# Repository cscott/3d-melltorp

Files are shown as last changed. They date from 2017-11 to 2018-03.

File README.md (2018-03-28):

# Enclosure for 3d printer based on Ikea Melltorp tables

Thing tracker at:
https://cscott.github.io/thing-tracker/#/thing/6400396d-9777-424c-8209-8ab2d352c14b

## Description

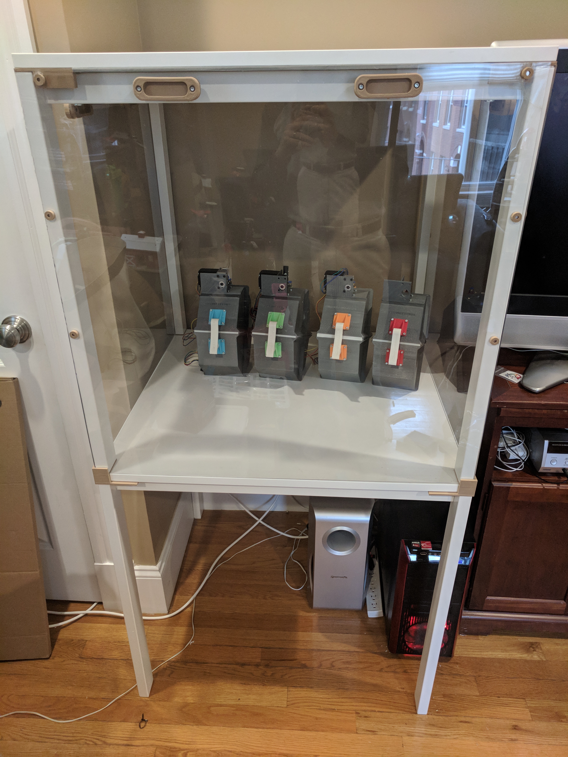
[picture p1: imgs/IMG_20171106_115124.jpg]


This repository contains a collection of parts used to create a 29.5"
x 29.5" 3D printer enclosure based on IKEA [Melltorp] tables.  It was
inspired by the many similar designs for enclosures based on the IKEA
[Lack] tables, but my modified Printrbot Simple Metal printer is a bit
too large to fit in the 22" x 22" space provided by the Lack.

You will need two Melltorp tables.  You could probably stack these
three high if you wanted an enclosure for two printers.

<br clear="both" />

## Instructions

### Step 1: Assemble bottom table.

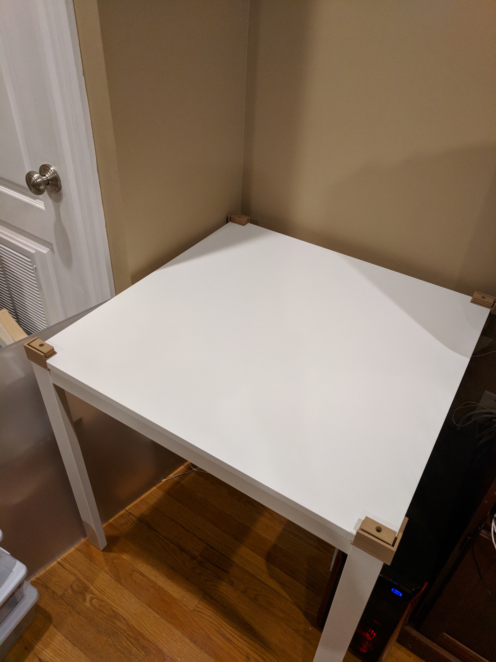
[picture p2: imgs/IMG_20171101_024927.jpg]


Follow the Ikea instructions for assembling the bottom table.  After
assembly, flip the table upright and unscrew the four allen-head bolts
attaching the tabletop to the leg assembly.  Slide four printer leg
holder pieces ([`melltorp-above-wrap.stl`]; 2 of these will need to be
mirrored) over the corners of the
table, inserting the white Ikea spacers into the cutouts provided,
then reattach the tabletop using the allen-head bolts.

<br clear="both" />
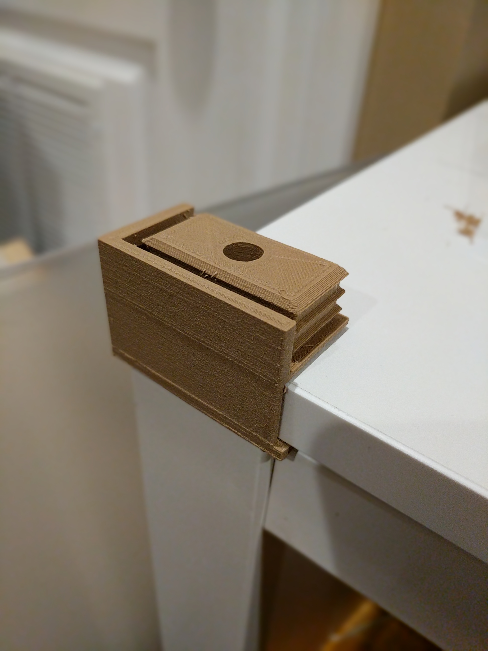
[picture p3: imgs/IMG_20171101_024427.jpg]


Alternatively, you could use [`melltorp-above.stl`] and screw the leg
holders directly into the table top. (Again, two should be printed out
as mirror images.)

<br clear="both" />

### Step 2: Assemble top table.

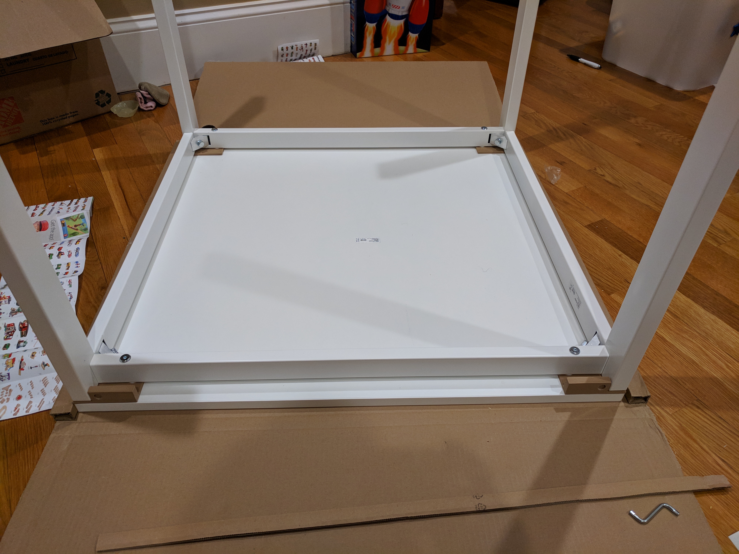
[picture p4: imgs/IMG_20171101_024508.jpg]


Again, follow the Ikea instructions to assemble the top table, but
sandwich the four magnet holders ([`melltorp-below.stl`], 2 will be mirrored)
between the
legs and tabletop, using the white Ikea spacers in the provided
cutouts for alignment. I also recommend using [foam sealing tape]
between the table frame and table top to seal the gap.

<br clear="both" />
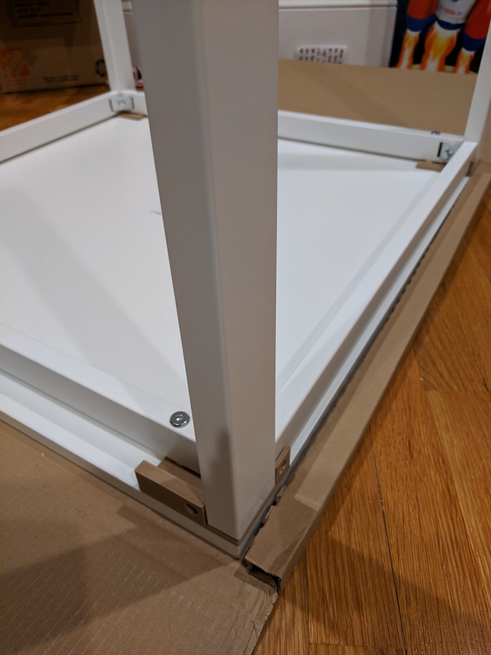
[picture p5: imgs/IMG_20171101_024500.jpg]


<br clear="both" />

### Step 3: Stack the tables

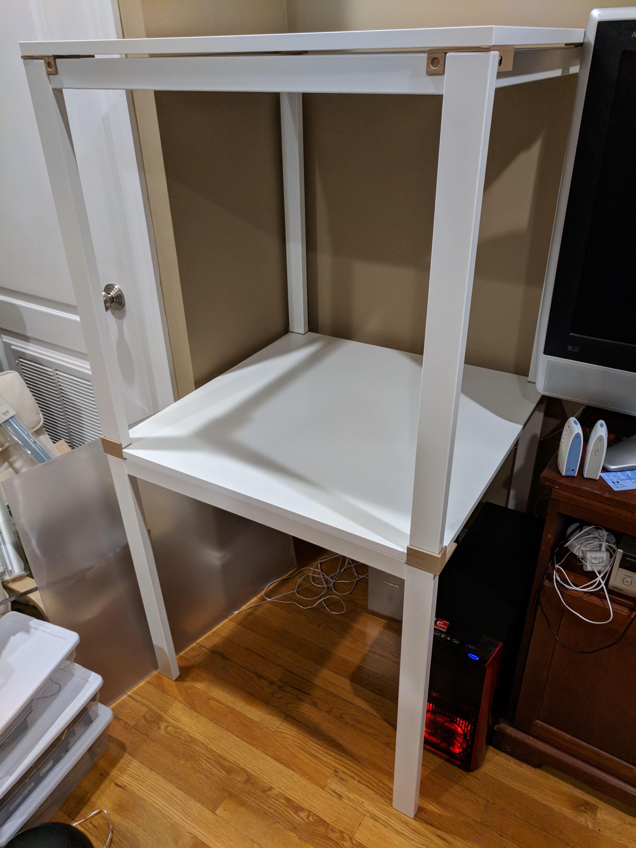
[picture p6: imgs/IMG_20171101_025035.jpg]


Pry off the white plastic caps on the end of each leg on the top
table, then stack the top table on top of the bottom table.

<br clear="both" />

### Step 4: Trim plexiglass

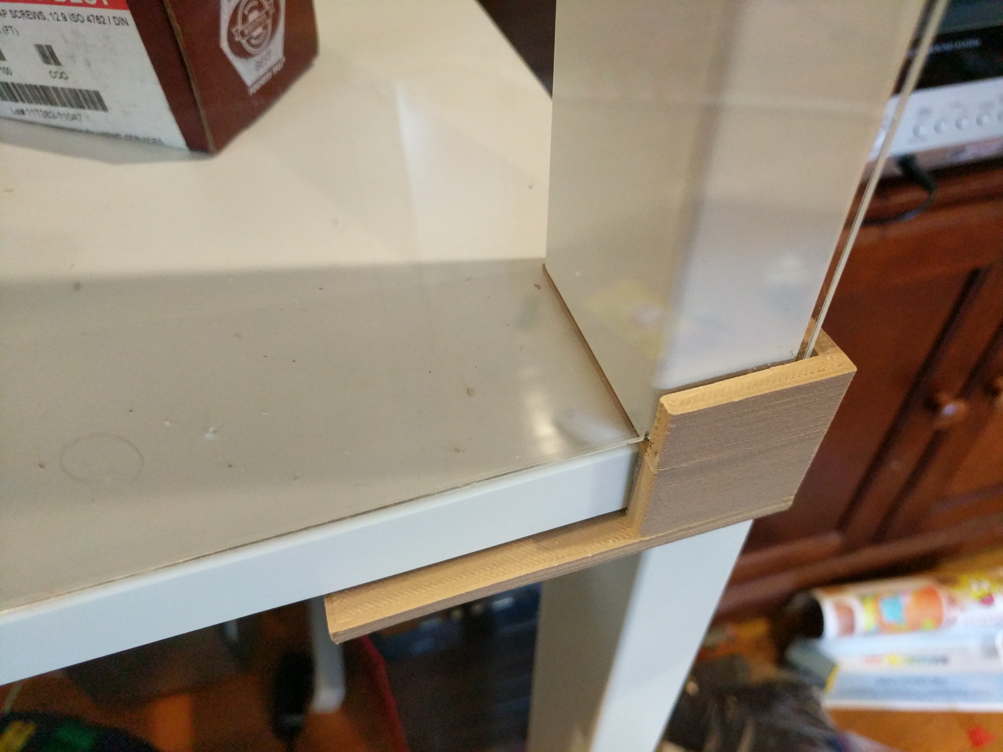
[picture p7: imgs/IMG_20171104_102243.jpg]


Trim 4 sheets of [28"x30" plexiglass] to 28" x 29.25".  (Note that the
link goes to Lowe's, which sells "30in x 30in" sheets of plexiglass
which are really 28" x 30".  If you get your plexiglass from a
different source, you might want to extend the 28" side up to 28.5"
for a better seal.)

The bottom of the plexiglass will slide into the space between the
table legs and the leg holder.

<br clear="both" />

### Step 5: Install magnets

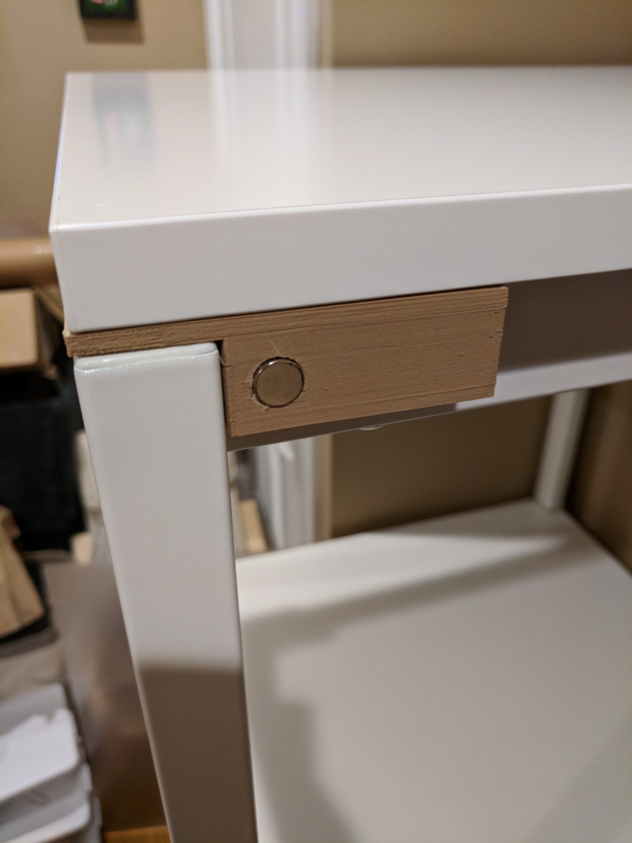
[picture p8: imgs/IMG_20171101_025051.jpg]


Insert magnets into the indents by the table legs.  Take care to
ensure the polarities of the magnets are consistent.

<br clear="both" />
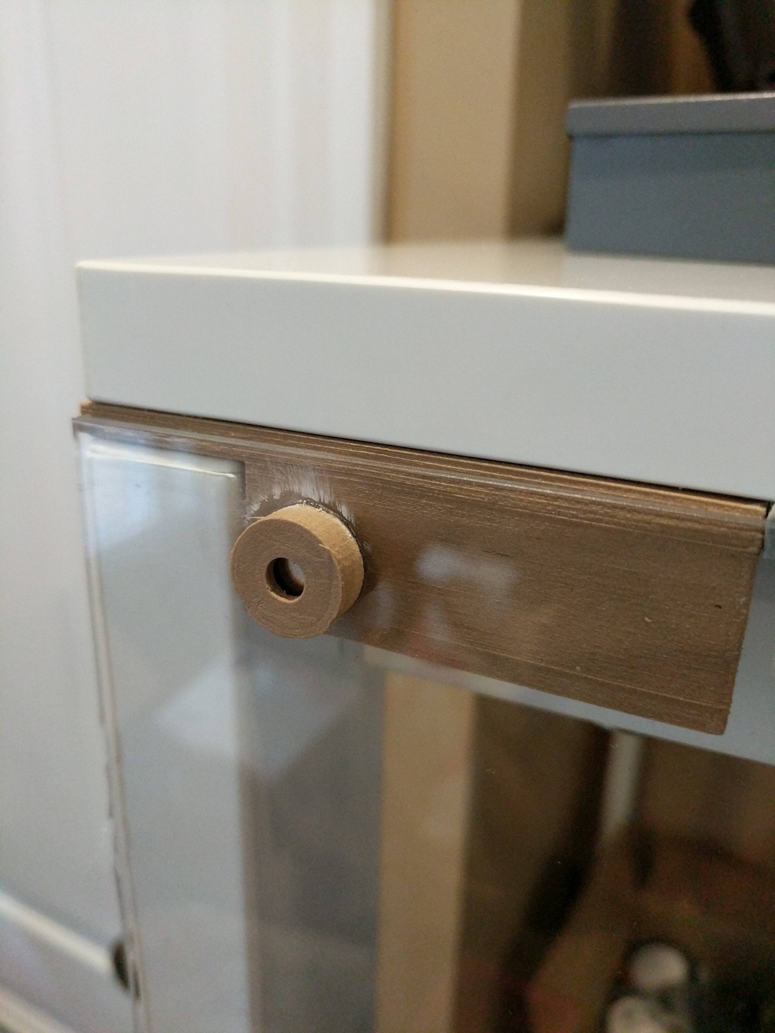
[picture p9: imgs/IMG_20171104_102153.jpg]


Now insert
magnets into the magnet mount rings ([`melltorp-holder.stl`]), again
taking care to ensure that the polarity is consistent and that the
open end of the mount ring is attracted to the open side of the table
leg magnets.  Slide the plexiglass into the channels at the bottom,
and use the mounted magnets to secure the top of the plexiglass.  Use
some superglue to affix the magnet mounts permanently to the
plexiglass once you have things lined up.

<br clear="both" />
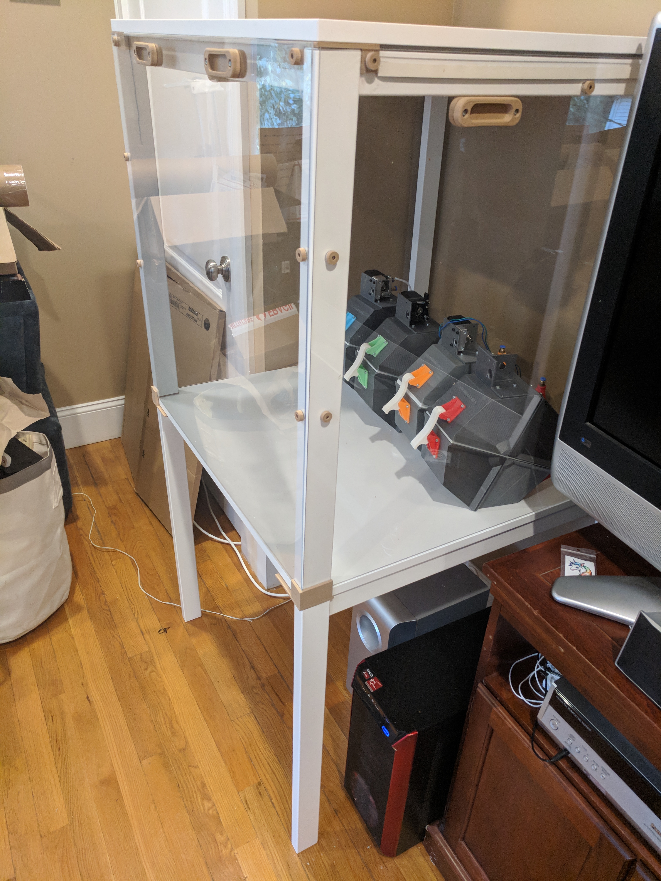
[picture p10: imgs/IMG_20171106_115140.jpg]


I also added a pair of mounted magnets 8" and 16" down from the top
of the leg, in order to better seal the sides of the plexiglass.
For the side pieces, I added some [foam sealing tape], and superglued
one magnet directly to the table frame.  A mounted magnet glued to
the plexiglass at this same spot helps keep the plexiglass pressed
into the foam tape.

<br clear="both" />

### Step 6: Install handles

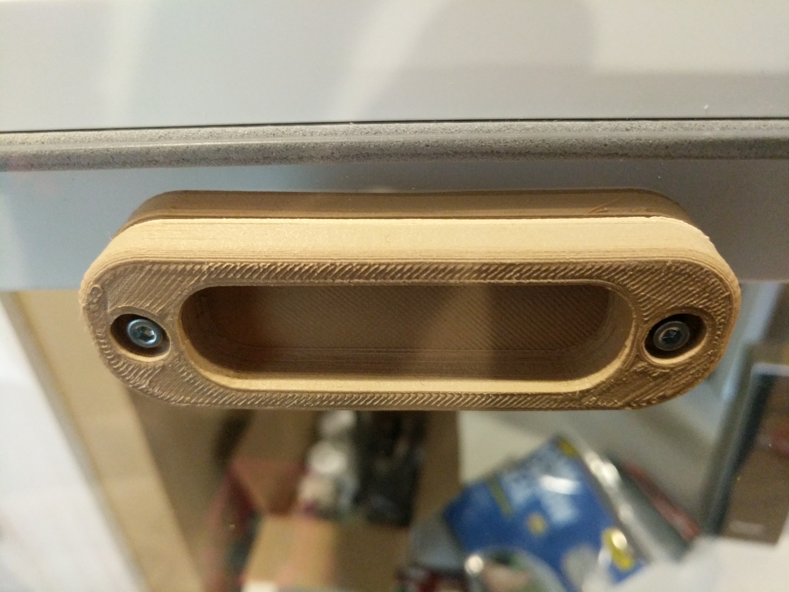
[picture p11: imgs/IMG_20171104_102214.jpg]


Use M3 x 12mm socket head screws and M3 nuts to attach handles
([`melltorp-handle-top.stl`]) to either side of the plexiglass.
Note that I had some issues with the plexiglass cracking when I
drilled the screw holes for mounting; I recommend supergluing
one side to the plexiglass and then using it as a guide when
drilling.  The glued side would prevent any crack from spreading,
but it also seems to prevent cracking in the first place.

<br clear="both" />
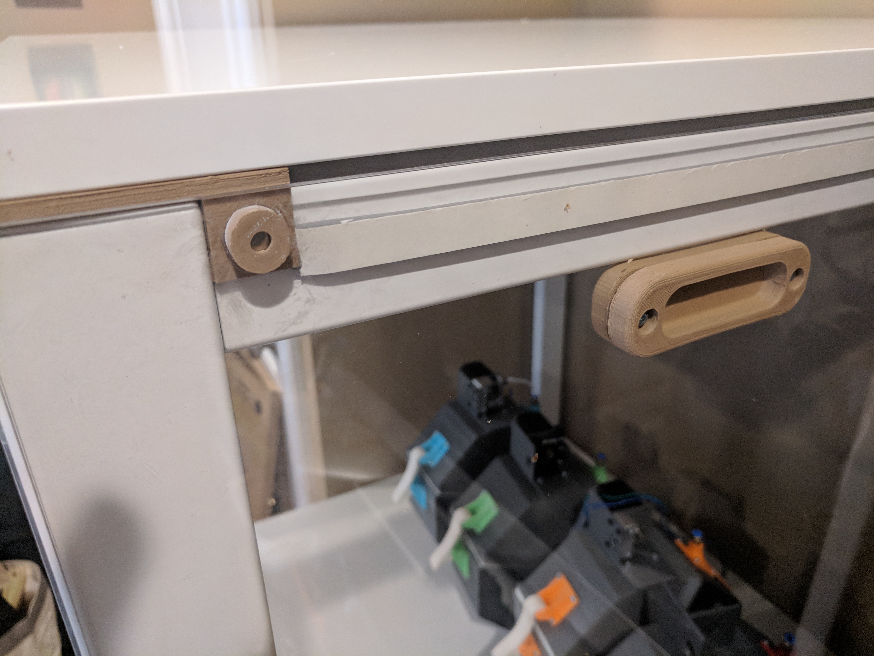
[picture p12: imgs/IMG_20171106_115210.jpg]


I find it most convenient to have a handle for gripping on both
sides of the plexiglass, so I can easily lift the sheets into
place or out of the way, but if you want to save some printing
time you can glue handles on only one side, or else use
[`melltorp-handle-bottom.stl`] on the back side.

<br clear="both" />

## Related

* [An excellent printer enclosure using a Lack table](https://www.thingiverse.com/thing:1843235).

## License

These designs are licensed under the [GPLv2+].

[Lack]: http://www.ikea.com/us/en/catalog/products/20011408/
[Melltorp]: http://www.ikea.com/us/en/catalog/products/S39011781/
[28"x30" plexiglass]: https://www.lowes.com/pd/OPTIX-0-08-in-x-30-in-x-30-in-Clear-Acrylic-Sheet/3978817
[10x3mm magnets]: https://amazon.com/gp/product/B01MFHNHNW/
[foam sealing tape]: https://amazon.com/gp/product/B00005202Y
[`melltorp-above-wrap.stl`]: ./melltorp-stl/melltorp-above-wrap.stl
[`melltorp-above.stl`]: ./melltorp-stl/melltorp-above.stl
[`melltorp-below.stl`]: ./melltorp-stl/melltorp-below.stl
[`melltorp-holder.stl`]: ./melltorp-stl/melltorp-holder.stl
[`melltorp-handle-top.stl`]: ./melltorp-stl/melltorp-handle-top.stl
[`melltorp-handle-bottom.stl`]: ./melltorp-stl/melltorp-handle-bottom.stl
[GPLv2+]: https://spdx.org/licenses/GPL-2.0+.html

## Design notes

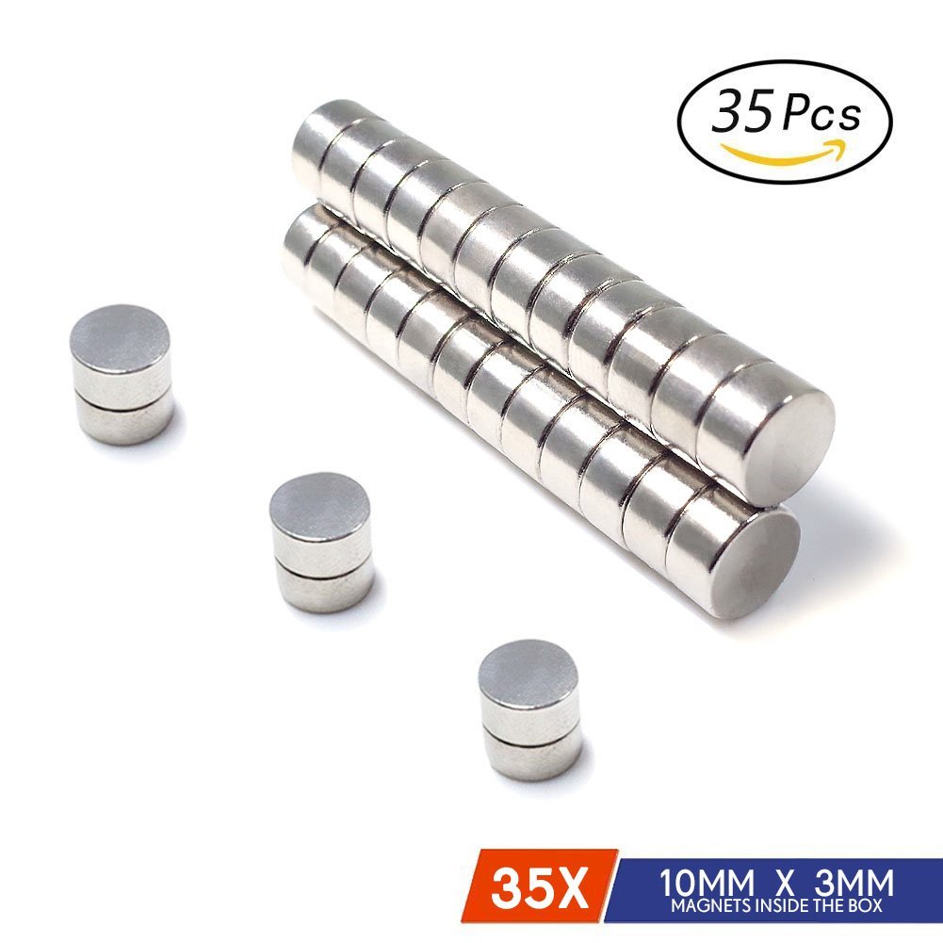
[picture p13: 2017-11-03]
imgs/magnets.jpg

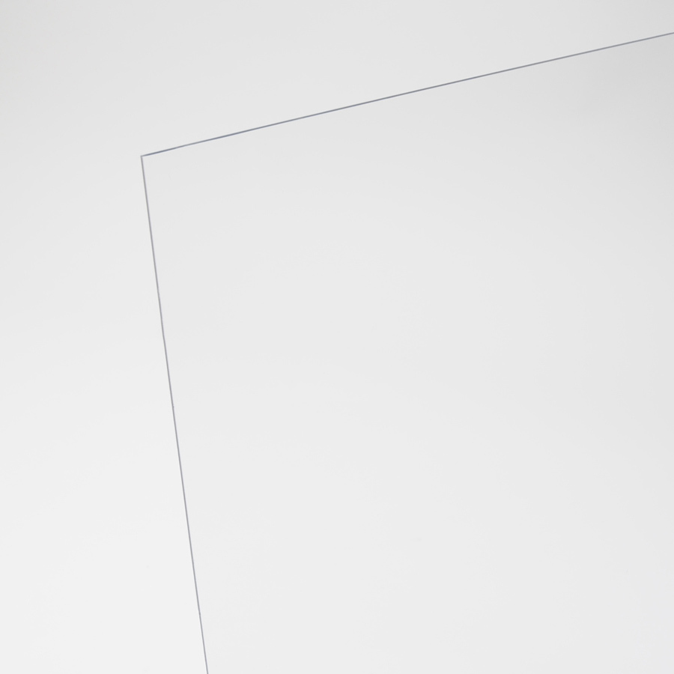
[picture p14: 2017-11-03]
imgs/plexiglass.jpg

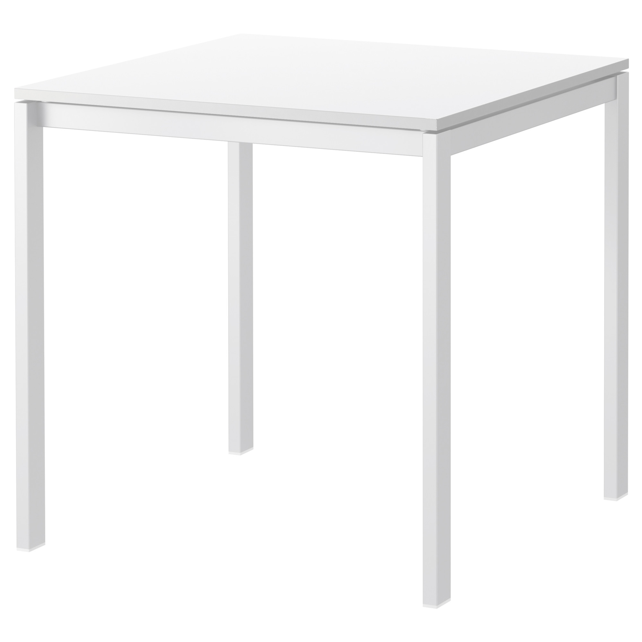
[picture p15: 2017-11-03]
imgs/melltorp.jpg

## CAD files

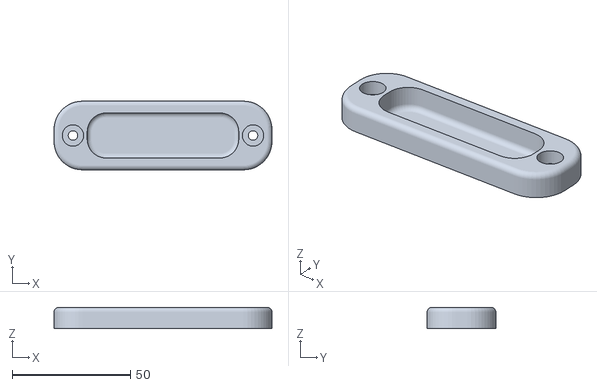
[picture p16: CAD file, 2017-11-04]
melltorp-stl/melltorp-handle-top.stl
92.0 x 29.0 x 9.00

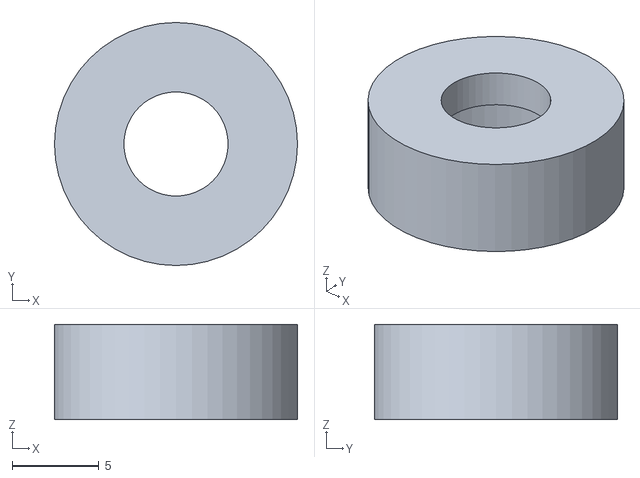
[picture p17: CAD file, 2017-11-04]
melltorp-stl/melltorp-holder.stl
14.0 x 14.0 x 5.50

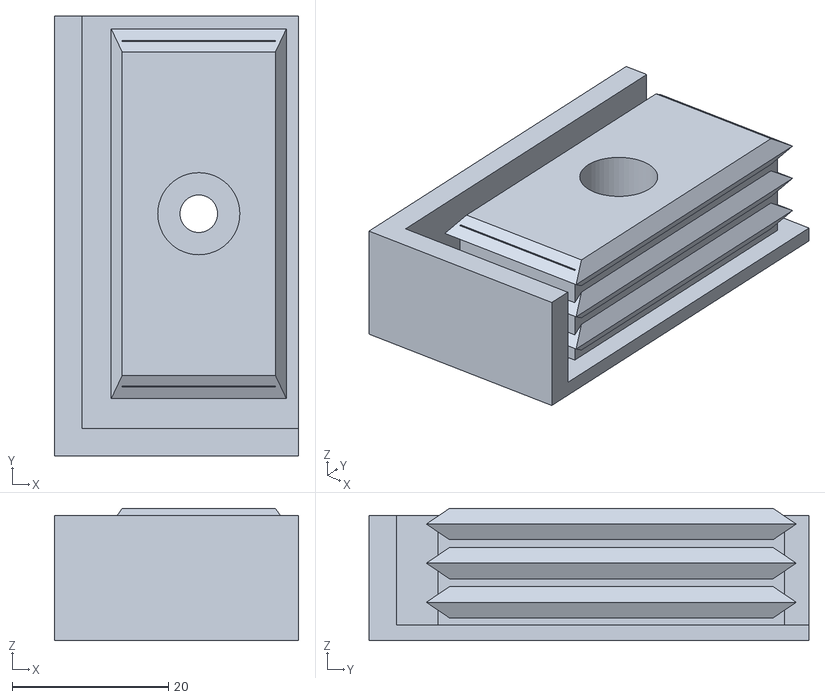
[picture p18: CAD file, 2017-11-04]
melltorp-stl/melltorp-above.stl
31.2 x 56.2 x 16.9

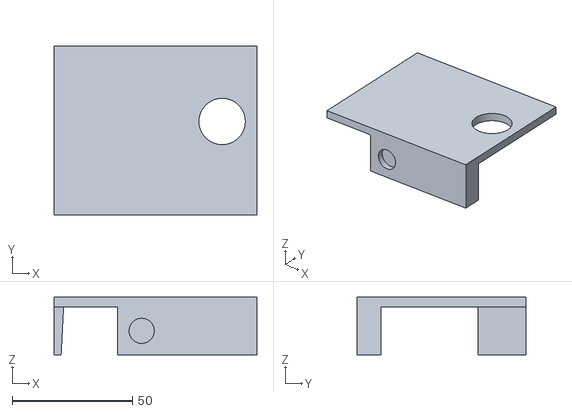
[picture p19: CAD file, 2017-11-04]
melltorp-stl/melltorp-below.stl
84.5 x 70.5 x 24.0

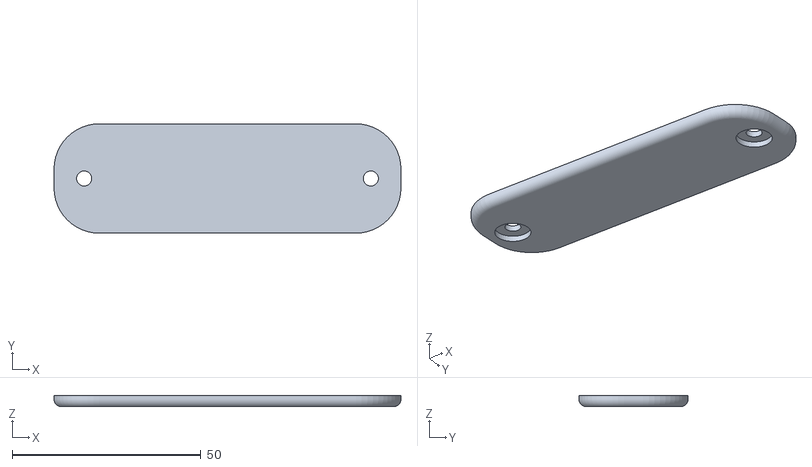
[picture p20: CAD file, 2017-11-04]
melltorp-stl/melltorp-handle-bottom.stl
92.0 x 29.0 x 3.00

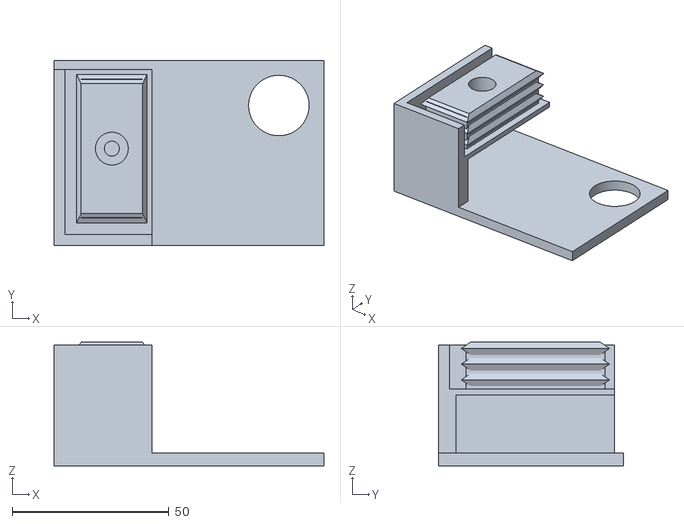
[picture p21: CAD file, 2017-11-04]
melltorp-stl/melltorp-above-wrap.stl
86.1 x 59.1 x 39.4

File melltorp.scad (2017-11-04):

/* 3d printer enclosure from Ikea Melltorp table. Connector pieces. */

/* [Global] */
part = "holder"; // [above:Leg coupler (above table top),above-wrap:Leg coupler (wraps around table top),below:Magnet holder (below table top),holder:Magnet mount (on plexiglass),handle-top:Outside handle,handle-bottom:Inside handle]

/* [Hidden] */
function inch() = 25.4;
function inner_clear() = 0.5; // how much larger to make holes
$fn = 48;

function middle_thick() = 4; // a bit of clearance from ring_thick()
function magnet_diam() = 10;
function magnet_depth() = 3;
function magnet_margin() = 5;

function ring_inset() = [70,39];
function ring_extra() = [5,22];
function ring_diam() = 17.8 + 1/*clearance*/;
function ring_thick() = 6.1; /* measured */

function leg_inset() = [4,0]; // from 70.2 to 69.4
function table_thick() = 18.5; // 18.2 with a little bit of clearance
function plexi_thick() = 2.2; // including clearance (measured 1.8mm)
function above_thick() = 2; // thickness underneath leg holder
function plexi_guide_thick() = 3.5;


piece(which=part);

module piece(which="both") {
  if (which=="below" || which=="both") {
    below_bracket();
  }
  if (which=="above" || which=="above-wrap" || which=="both") {
    above_bracket();
  }
  if (which=="above-wrap" || which=="both") {
    above_wrapper(shrink=(which=="above-wrap"));
  }
  if (which=="holder") {
    magnet_holder();
  }
  if (which=="handle-top" || which=="handle-both") {
    plexi_handle(is_top=true);
  }
  if (which=="handle-bottom" || which=="handle-both") {
    translate([0,0,-2]) // thickness of plexi
    plexi_handle(is_top=false);
  }
}

module middle(wall=[0,0], extra=[0,0]) {
  inset = ring_inset();
  margin = ring_extra();
  difference() {
    translate([-wall.x,-wall.y,0])
    cube([inset.x + ring_diam()/2 + margin.x + wall.x - extra.x,
          inset.y + ring_diam()/2 + margin.y + wall.y - extra.y,
          middle_thick()]);
    translate([inset.x,inset.y,-1])
      cylinder(d=ring_diam() + inner_clear(), h=middle_thick() + 2);
  }
}

module below_bracket() {
  magnet_y = 14;
  height = magnet_y + magnet_diam()/2 + magnet_margin();
  width = magnet_diam() + 2*magnet_margin();
  extra_width = 38; /* for side holder x axis */
  epsilon=.1;
  middle();
  // front holder
  difference() {
    translate([0,50.5,middle_thick()-height])
      cube([4,width,height-epsilon]);
    translate([3,50.5-epsilon,middle_thick()-height-epsilon])
      rotate([0,atan2(1,height-middle_thick()),0]) // 1mm over height-middle_thick() mm
      cube([2,width+2*epsilon,height+epsilon]);
    translate([-epsilon, 50.5 + width/2, middle_thick() - magnet_y])
      rotate([0,90,0])
      cylinder(d=magnet_diam() + inner_clear(), h=magnet_depth() + epsilon);
  }
  // side holder
  difference() {
    translate([26.5,0,middle_thick()-height])
      cube([width + extra_width,10,height-epsilon]);
    translate([26.5 + width/2, -epsilon, middle_thick() - magnet_y])
      rotate([-90,0,0])
      cylinder(d=magnet_diam() + inner_clear(), h=magnet_depth() + epsilon);
  }
}

module above_wrapper(shrink=false) {
  leg_outer_size = [25.5, 50.5];
  size = leg_inset() + leg_outer_size;
  wall = [-(leg_inset().x - plexi_thick() - plexi_guide_thick()),
          -(leg_inset().y - plexi_thick() - plexi_guide_thick())];
  epsilon = .1;
  difference() {
    translate([-wall.x,-wall.y,0])
      cube([size.x+wall.x,size.y+wall.y,middle_thick() + table_thick() + above_thick() - epsilon]);
    translate([0,0,middle_thick() - epsilon])
      cube([size.x + epsilon, size.y + epsilon, table_thick() + 2*epsilon]);
  }
  middle(wall=wall, extra=shrink?[0,17]:[0,0]);
}

module above_bracket() {
  leg_outer_size = [25.5, 50.5];
  leg_inner_size = [22.4, 47.3];
  leg_core_size = [19.6,44.3];
  leg_holder_height = 14;
  plexi_guide_height = 14;
  screw_hole = 4.3; // measured 3.8
  screw_head_hole = 10; // measured 7.8
  screw_deep = 4;
  epsilon=.1;
  difference() {
  union() translate([0,0,middle_thick() + table_thick()]) {
    *cube([leg_inset().x + leg_outer_size.x,
          leg_inset().y + leg_outer_size.y,
          above_thick()]);
    translate([leg_inset().x + leg_outer_size.x/2,
               leg_inset().y + leg_outer_size.y/2,
               above_thick()-epsilon]) {
      translate([0,0,(leg_holder_height + epsilon)/2])
      cube([leg_core_size.x, leg_core_size.y, leg_holder_height + epsilon],
           center=true);
      // groovy things
      for (i=[0:2]) translate([0,0,5*i + 3])
        for (j=[-1,1]) scale([1,1,j])
          linear_extrude(height=2, scale=leg_core_size.x/leg_inner_size.x)
            square([leg_inner_size.x, leg_inner_size.y], center=true);
      // plexi guide
      difference() {
        translate([-leg_outer_size.x/2 - plexi_thick() - plexi_guide_thick(),
                   -leg_outer_size.y/2 - plexi_thick() - plexi_guide_thick(),
                   -(above_thick()-epsilon)])
          cube([leg_outer_size.x + plexi_thick() + plexi_guide_thick(),
                leg_outer_size.y + plexi_thick() + plexi_guide_thick(),
                plexi_guide_height + above_thick()]);
        translate([-leg_outer_size.x/2 - plexi_thick(),
                   -leg_outer_size.y/2 - plexi_thick(),
                   epsilon])
          cube([leg_outer_size.x + plexi_thick() + epsilon,
                leg_outer_size.y + plexi_thick() + epsilon,
                plexi_guide_height + epsilon]);
      }
    }
  }
  // screw hole
  translate([leg_inset().x + leg_outer_size.x/2,
             leg_inset().y + leg_outer_size.y/2,
             middle_thick() + table_thick() - epsilon]) {
    cylinder(d=screw_hole + inner_clear(),
             h=above_thick() + leg_holder_height + 2*epsilon);
    translate([0,0,screw_deep])
      cylinder(d=screw_head_hole + inner_clear(),
               h=above_thick() + leg_holder_height + 2*epsilon);
  }
  }
}

module magnet_holder() {
  epsilon = .1;
  margin = 2;
  inset = -0.5;
  difference() {
    cylinder(d=magnet_diam() + 2*margin, h=magnet_depth() - inset + margin);
    translate([0,0,-epsilon]) {
      cylinder(d=magnet_diam() + inner_clear(), h=magnet_depth() - inset + epsilon);
      cylinder(d=magnet_diam() - 2*margin, h=magnet_depth() - inset + margin + 2*epsilon);
    }
  }
}

module plexi_handle(is_top=true) {
  width=90; height=27; depth=is_top ? 10 : 4;
  round=2;
  inset=[14, 5, 1.5/*floor thickness*/];
  scale([1,1,is_top?1:-1])
  difference() {
    translate([0,0,depth/2-round]) {
      round_rect([width, height, depth], r=[round, round, 10], center=true);
    }
    translate([0,0,-round]) {
      cube([width*2, height*2, round*2], center=true);
    }
    if (is_top) translate([0,0,depth + inset.z])
      round_rect([width-2*inset.x, height-2*inset.y, 2*depth], r=[round, round, 6], center=true);
    for (i=[1,-1]) scale([i,1,1]) translate([width/2 - inset.x/2, 0, 0]) {
      translate([0,0,-1])
        cylinder(d=4, h=depth+2);
      translate([0,0,is_top ? 4 : 1.5])
        cylinder(d=9, h=depth);
    }
  }
}

function max(x,y) = (x > y) ? x : y;

// uses the same radius for x and y, but we can live with that.
module round_rect(size=[1,1,1], r=[0,0,0], center=false) {
  s = size; // abbreviation
  r2 = max(r.x, r.y); // XXX sigh
  minkowski() {
    round_rect2a([s.x-r2, s.y-r2, s.z-r2], r.z);
    sphere(r=r2);
  }
}

// XXX the corners in this are sharp. :(
module round_rect2(size=[1,1,1], r=[0,0,0], center=false) {
  s = size; // abbreviation
  s2 = size/2;
  d = 2*r;
  translate(center ? [0,0,0] : [s2.x, s2.y, s2.z]) intersection() {
    round_rect2a([s.x, s.y, s.z], r.z);
    rotate([90,0,0]) round_rect2a([s.x, s.z, s.y], r.y);
    rotate([0,90,0]) round_rect2a([s.z, s.y, s.x], r.x);
  }
}

module round_rect2a(s, r) {
  if (r > 0) {
    cube([s.x-2*r, s.y, s.z], center=true);
    cube([s.x, s.y-2*r, s.z], center=true);
    for (i=[1,-1]) for (j=[1,-1]) scale([i,j,1])
      translate([s.x/2 - r, s.y/2 - r, 0])
        cylinder(r=r, h=s.z, center=true);
  } else {
    cube([s.x, s.y, s.z], center=true);
  }
}
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

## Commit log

2017-11-03 3d printer enclosure based on Ikea Melltorp tables.
    [melltorp.scad]
2017-11-03 Basic thing-tracker support.
    [melltorp-above-wrap.stl, melltorp-above.stl, melltorp-below.stl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]
2017-11-04 Add magnet holder and handle.
    [melltorp.scad]
2017-11-04 Tweaks to handle and holders.
    [melltorp-above-wrap.stl, melltorp-above.stl, melltorp-below.stl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]
2017-11-04 Update instructions to describe holders and handles.
    [melltorp-handle-top.stl, melltorp.scad]
2018-03-28 Clarify that 2 of the 4 leg pieces need to be mirrored.
